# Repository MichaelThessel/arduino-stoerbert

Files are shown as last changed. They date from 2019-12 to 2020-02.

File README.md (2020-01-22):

# Intro

This repository contains the files required to build an easy to use MP3 player for small children.
This project is heavily inspired by [Hoerbert](https://en.hoerbert.com).

PCB CAD
Inside
Inside

Main components required to build:

* Arduino Uno
* Adafruit Music Maker shield
* Speaker
* Button PCB (see below)
* Volume Pot
* On/Off switch
* Battery holders
* Hookup wire

# Button PCB schematics

I created a custom PCB for the input buttons. The schematics for that are in the
cad directory in KiCad format. The Arduino UNO does not have enough GPIO pins
for the Music Maker shield, the volume pot, and 12 buttons. To reduce the amount
of GPIO pins required for the buttons I used 2 shift registers. That reduces the
amount of required pins for the buttons to 3.

I used the following components:

* [2x CD4021BC shift registers](http://www.redrok.com/CMOS_CD4021BC_8-StageStaticShiftRegister_Fairchild.pdf)
* [OmronB3F Buttons](https://www.amazon.ca/gp/product/B07CW1XJTS)
* as well as some 0805 1k resistors

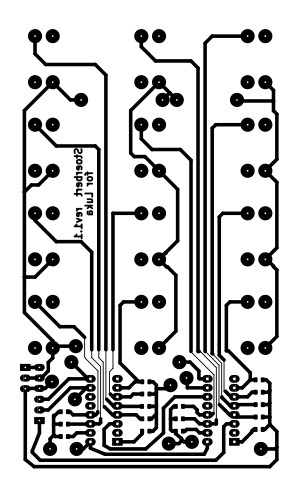
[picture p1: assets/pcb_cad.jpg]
PCB CAD

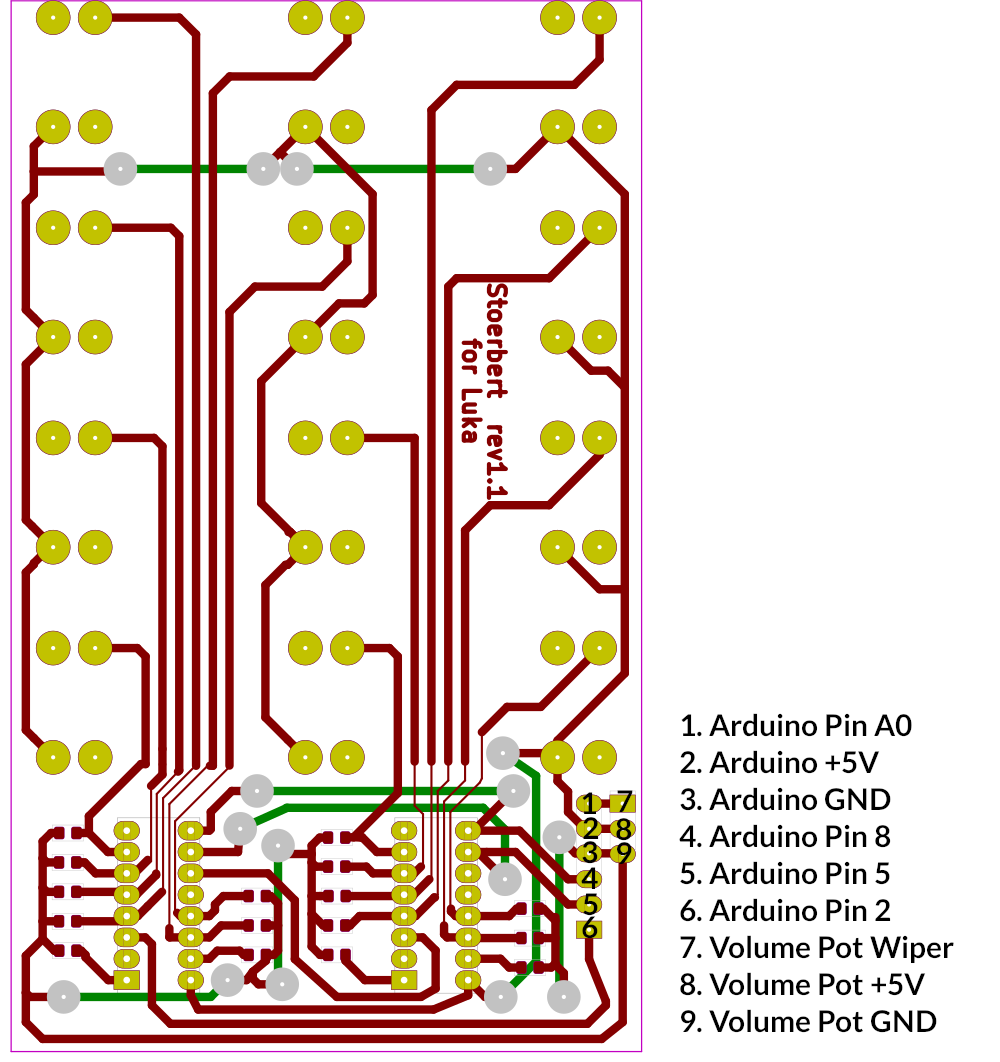
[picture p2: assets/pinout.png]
PCB Pinout

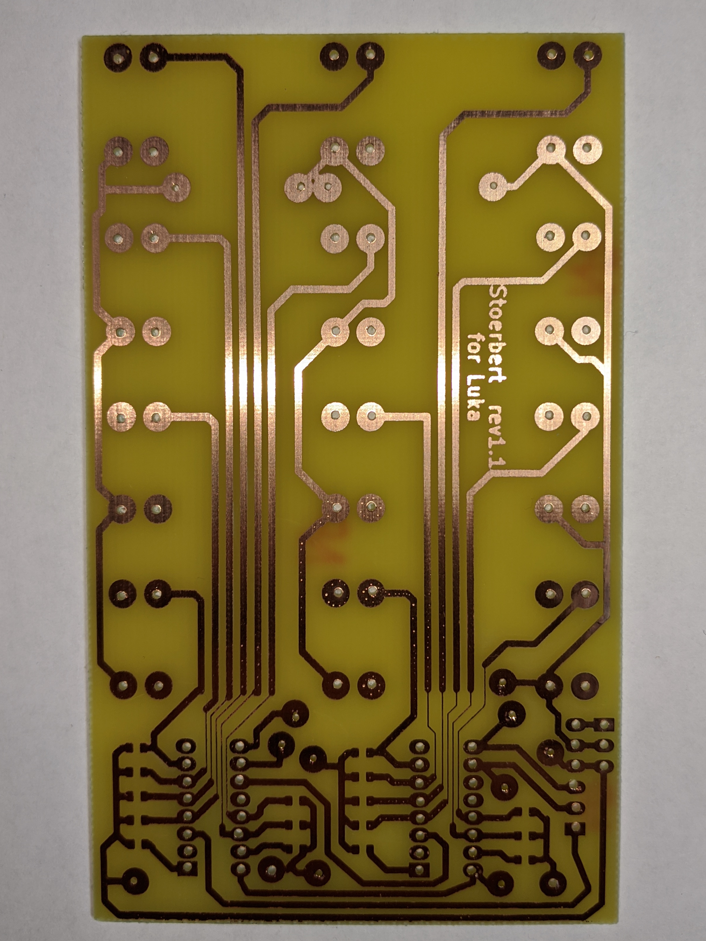
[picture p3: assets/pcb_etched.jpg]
PCB etched

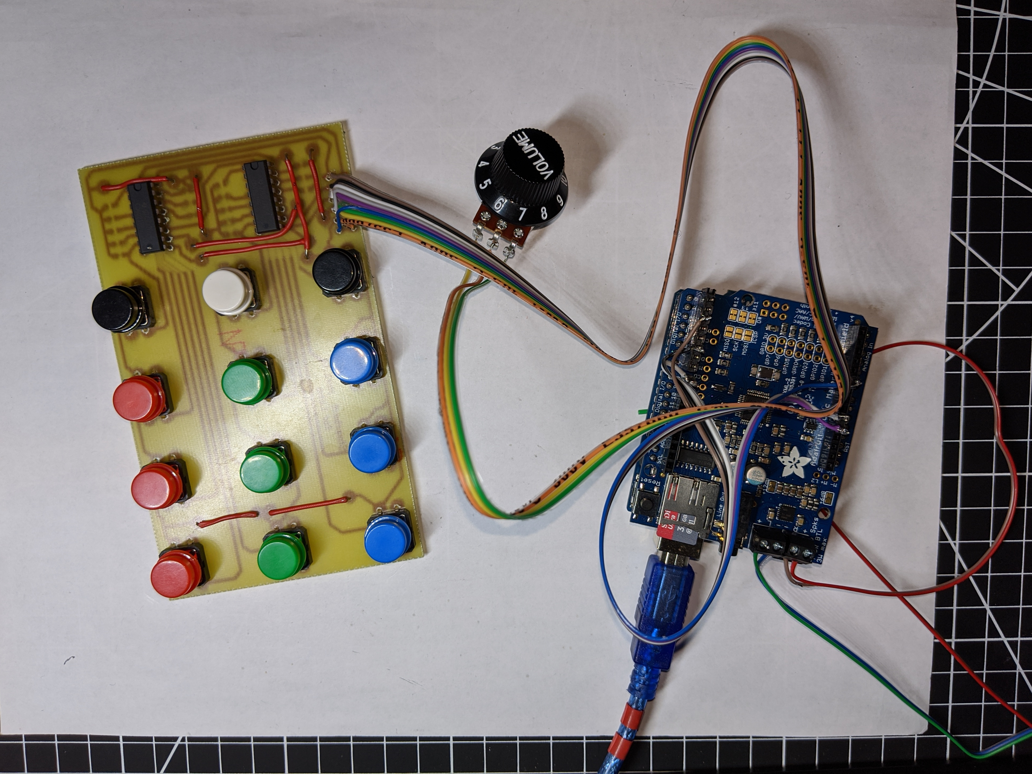
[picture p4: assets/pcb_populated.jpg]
PCB populated


If you want to etch the PCB yourself you can print this PDF on a transparency.
Make sure to use US letter sized transparencies if you use the PDF below.
Alternatively you can just create a new PDF from the KiCad layout.

[PCB transparency](/assets/pcb_cad.pdf)

I followed this [PCB etching process](https://www.youtube.com/watch?v=tWnfnt2rNO0)

# Button layout

## Regular mode

    [album 1]   [album 2]       [album 3]
    [album 4]   [album 5]       [album 6]
    [album 7]   [album 8]       [album 9]
    [prev]      [play_pause]    [next]

## God mode

    [1]         [2]             [3]
    [4]         [5]             [6]
    [7]         [8]             [9]
    [0]         [play_pause]    [next]

# God mode

The player supports 2 different modes. Regular mode and god mode.
In regular mode one album is assigned to each button. This is the default mode
and what the device is mainly intended for.
To add more functionality, god mode has been added. This mode allows to add an
alternative set of albums which makes it a handy MP3 player for parents as well.
In that mode instead of directly playing an album for each button press, the
buttons act as numerical input buttons. 2 buttons have to be pressed to select
an album. I.e. 4 - 2 to select album 42. Up to 99 albums are supported in
god mode.

To enter god mode the god mode sequence has to be pressed. The god mode sequence
is: prev - play_pause - play_ pause - next (regular mode keyboard layout). The
same sequence can be used to switch back to regular mode. When the sequence has
been entered correctly a short beep will sound.

# SD card

## Structure

The SD card needs to be formated with FAT32.

The root folder structure needs to be:

k01 ... k09 for the regular albums and

g01 ... g99 for the god mode albums

The files in each folder need to be named:

01.mp3 ... 99.mp3

i.e.

    /k06/01.mp3
    /k06/02.mp3
    /k06/03.mp3
    /k06/04.mp3
    /k06/05.mp3
    /k06/06.mp3

## Convert files to supported file format

    a=`find ./ -type f -name "*.mp3" | awk '{print "mv", "\""$0"\"", substr($0, 3, 2)".mp3;"}'`; eval $a

This only works if the files are named with the first 2 digits indicating their
track name already. I.e. `01-meshuggah-bleed.mp3`. A great alternative for batch
renaming the files is [Mp3Tag](https://www.mp3tag.de/en).

# Auto resume

The player will automatically resume the last played track after power off (if
powered off before an album finished playing).

# Power saving

To remind the user to turn of the device once the album has finished playing the
player will sound a short beep every 5 minutes once the last album has played.

# Mono mode

To keep the player compact and reduce power consumption this has been designed
to work with a single speaker. The Music Maker shield is configured to work in
mono mode. You can connect your speaker to either of the 2 speaker ports. In
case you want to build a stereo version you can simply remove these lines from
player.cpp

    // Enable mono mode
    vs1053.sciWrite(VS1053_REG_WRAMADDR, 0x1e09);
    vs1053.sciWrite(VS1053_REG_WRAM, 0x0001);

# Case build

I added an album of the full build on [Imgur](https://imgur.com/gallery/S2kZkn8)

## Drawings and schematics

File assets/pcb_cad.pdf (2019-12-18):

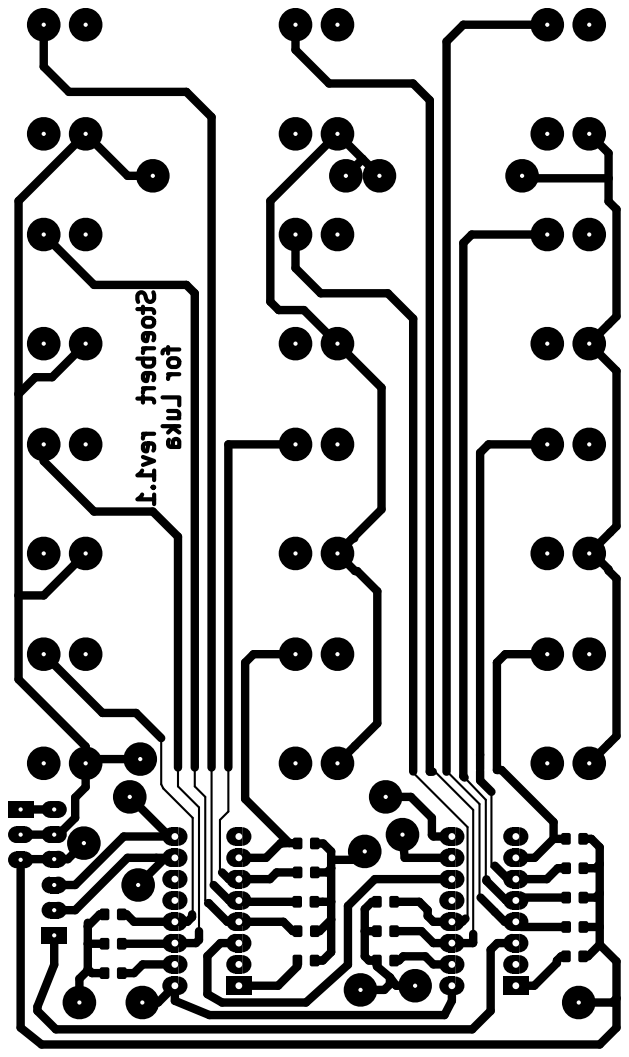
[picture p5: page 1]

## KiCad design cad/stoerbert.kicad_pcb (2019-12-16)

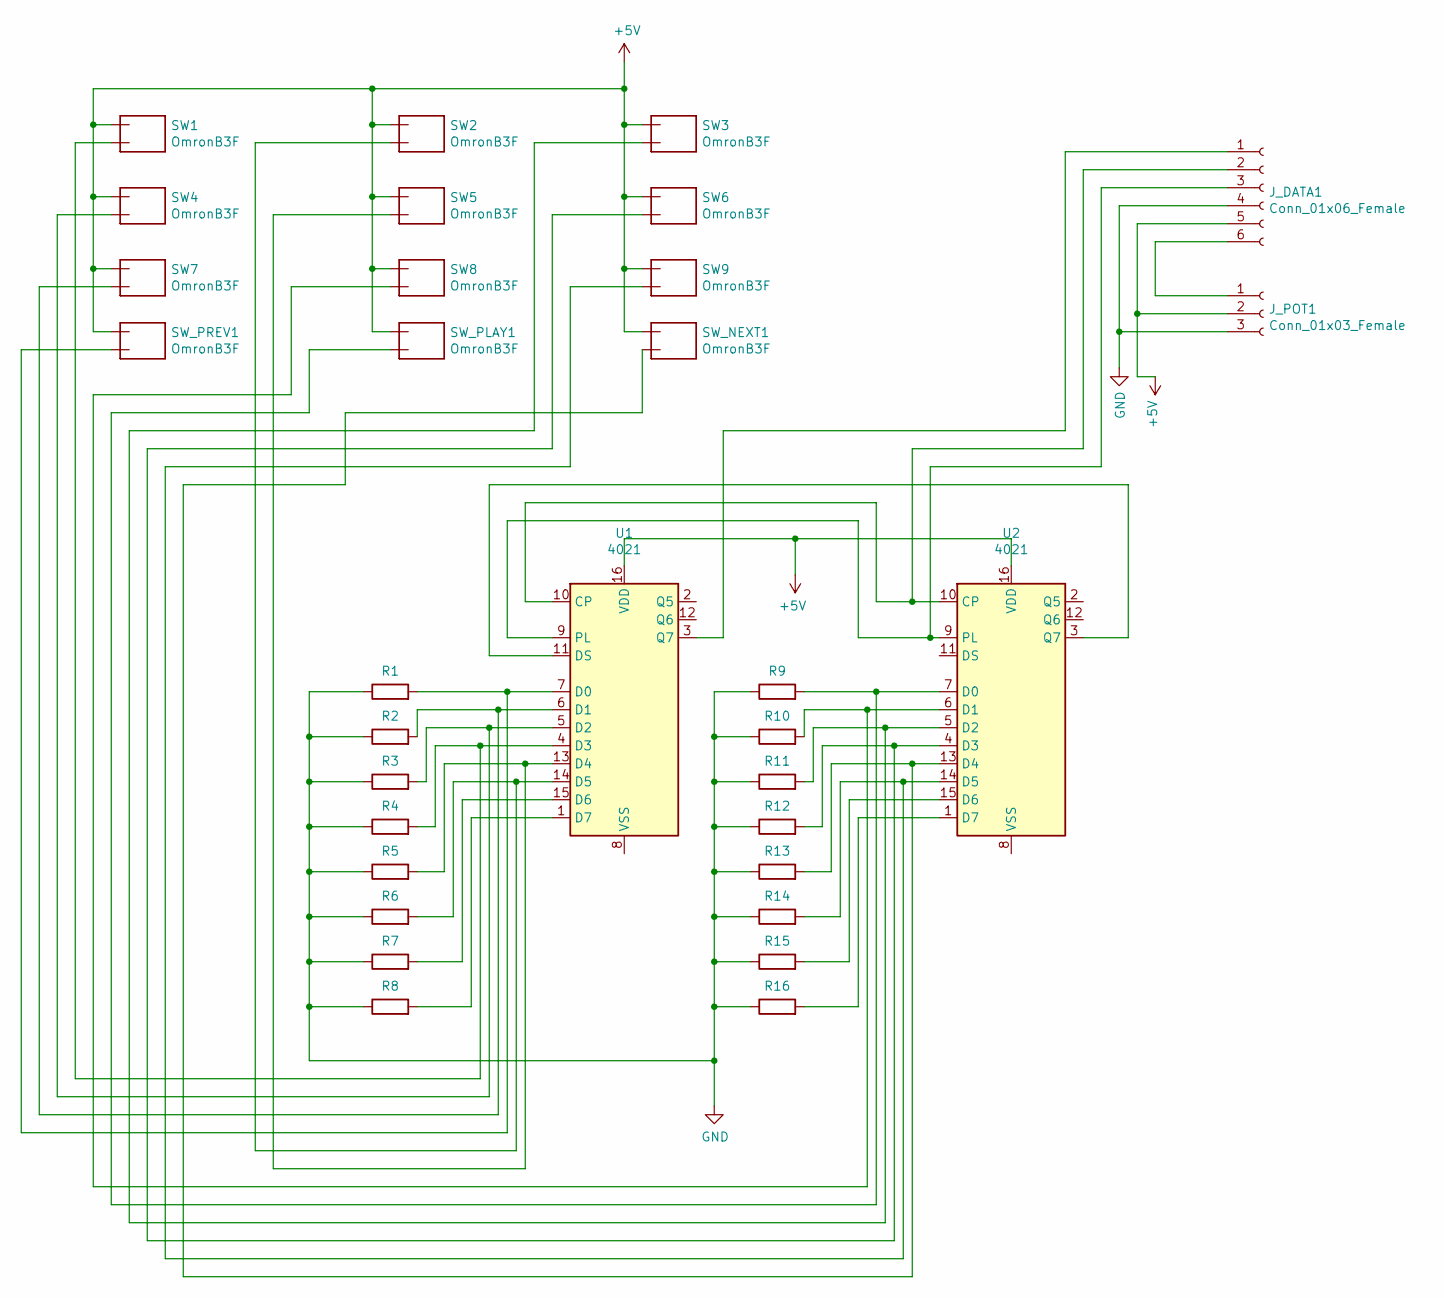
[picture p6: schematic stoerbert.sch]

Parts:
J_DATA1: Conn_01x06_Female; PinHeader_1x06_P2.00mm_Vertical
J_POT1: Conn_01x03_Female; PinHeader_1x03_P2.00mm_Vertical
R1: 1K; R_0805_2012Metric_Pad1.15x1.40mm_HandSolder
R2, R3: 1k; R_0805_2012Metric_Pad1.15x1.40mm_HandSolder
R4, R5, R6, R7, R8, R9, R10, R11, R12, R13, R14, R15, R16: R; R_0805_2012Metric_Pad1.15x1.40mm_HandSolder
SW1, SW2, SW3, SW4, SW5, SW6, SW7, SW8, SW9: OmronB3F; ToggleSwitch
SW_NEXT1: OmronB3F; ToggleSwitch
SW_PLAY1: OmronB3F; ToggleSwitch
SW_PREV1: OmronB3F; ToggleSwitch
U1, U2: 4021; DIP-16_W7.62mm_large

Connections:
+5V: J_DATA1.5, J_POT1.2, SW1.1, SW2.1, SW3.1, SW4.1, SW5.1, SW6.1, SW7.1, SW8.1, SW9.1, SW_NEXT1.1, SW_PLAY1.1, SW_PREV1.1, U1.16 (VDD), U2.16 (VDD)
GND: J_DATA1.4, J_POT1.3, R1.1, R2.1, R3.1, R4.1, R5.1, R6.1, R7.1, R8.1, R9.1, R10.1, R11.1, R12.1, R13.1, R14.1, R15.1, R16.1
unnamed: J_DATA1.1, U1.3 (Q7)
unnamed: J_DATA1.2, U1.10 (CP), U2.10 (CP)
unnamed: J_DATA1.3, U1.9 (PL), U2.9 (PL)
unnamed: J_DATA1.6, J_POT1.1
unnamed: R1.2, SW_PREV1.3, U1.7 (D0)
unnamed: R2.2, SW7.3, U1.6 (D1)
unnamed: R3.2, SW4.3, U1.5 (D2)
unnamed: R4.2, SW1.3, U1.4 (D3)
unnamed: R5.2, SW5.3, U1.13 (D4)
unnamed: R6.2, SW2.3, U1.14 (D5)
unnamed: R7.2, U1.15 (D6)
unnamed: R8.2, U1.1 (D7)
unnamed: R9.2, SW_PLAY1.3, U2.7 (D0)
unnamed: R10.2, SW8.3, U2.6 (D1)
unnamed: R11.2, SW3.3, U2.5 (D2)
unnamed: R12.2, SW6.3, U2.4 (D3)
unnamed: R13.2, SW_NEXT1.3, U2.13 (D4)
unnamed: R14.2, SW9.3, U2.14 (D5)
unnamed: R15.2, U2.15 (D6)
unnamed: R16.2, U2.1 (D7)
unnamed: U1.11 (DS), U2.3 (Q7)

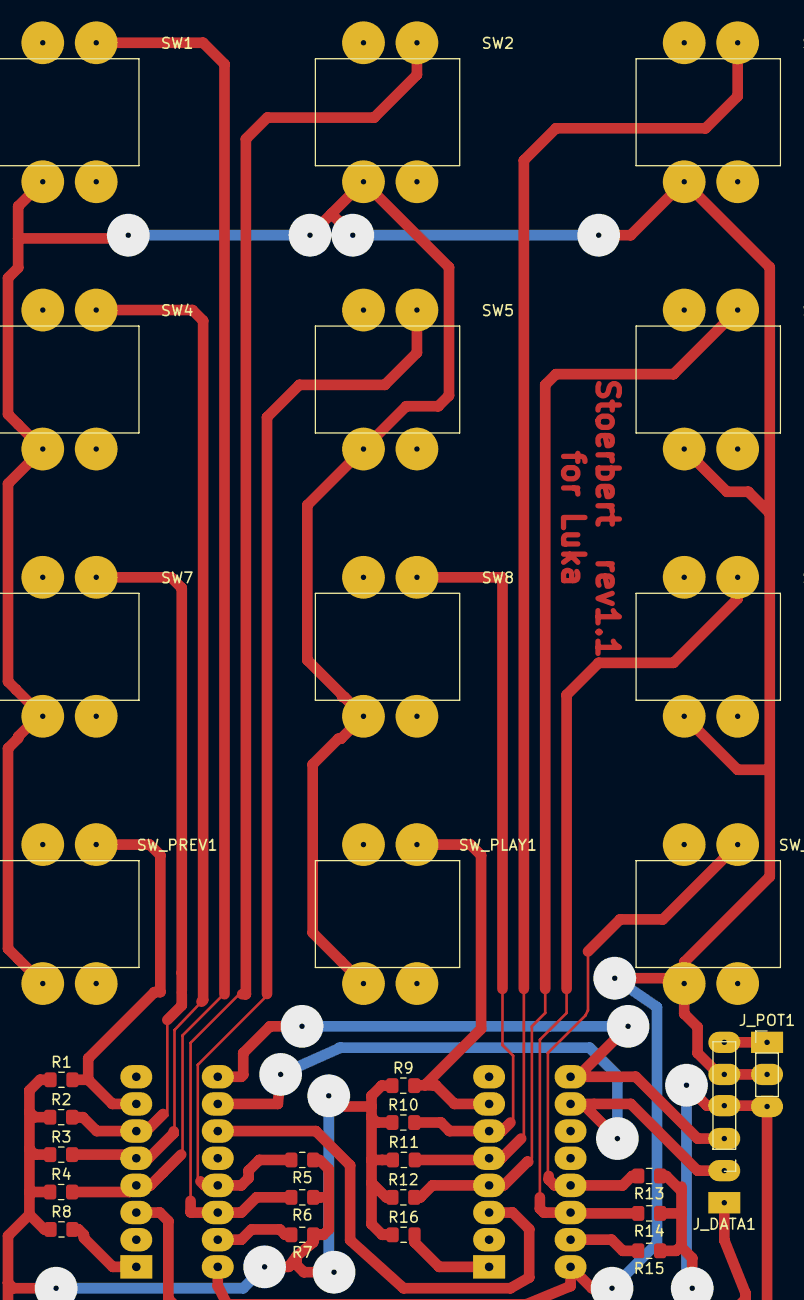
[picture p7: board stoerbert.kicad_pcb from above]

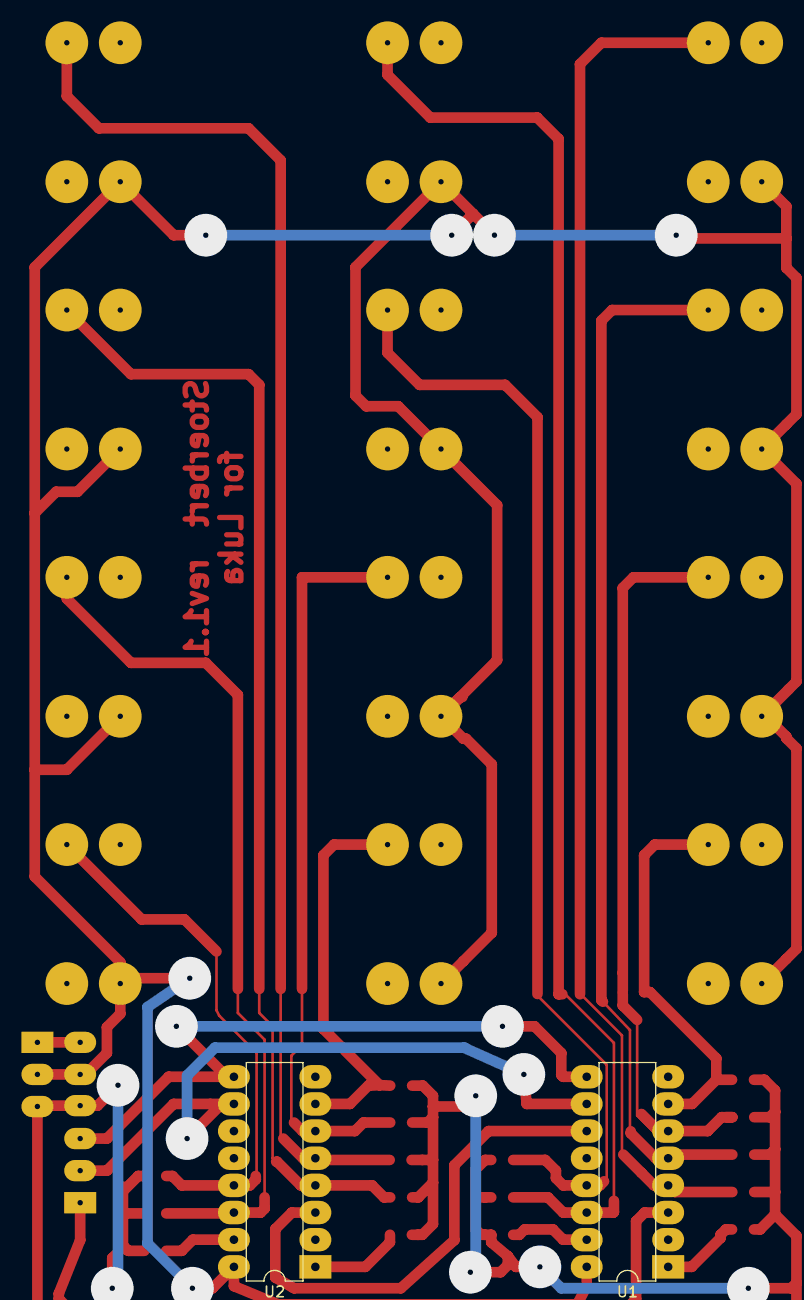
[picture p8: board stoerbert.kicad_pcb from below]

Board: 2 copper layers, 32 parts (2 on the bottom side), 23 nets.

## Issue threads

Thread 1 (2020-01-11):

Compile errors

GoremanX, 2020-01-11:
When trying to compile the sketch, the following warnings come up (full file path edited to protect privacy):

```sketch\player.cpp: In function 'void loadAlbum()':

sketch\player.cpp:89:35: warning: invalid conversion from 'void*' to 'char*' [-fpermissive]

         p.album[sequence] = malloc(strlen(entry.name()) + 1);

                             ~~~~~~^~~~~~~~~~~~~~~~~~~~~~~~~~

sketch\player.cpp: In function 'void powerReminder()':

sketch\player.cpp:235:39: warning: large integer implicitly truncated to unsigned type [-Woverflow]

         musicPlayer.sineTest(1000, 500);

                                       ^

sketch\player.cpp: In function 'void setupPlayer()':

sketch\player.cpp:410:63: warning: invalid conversion from 'const short unsigned int*' to 'const uint16_t* {aka const unsigned int*}' [-fpermissive]

     vs1053.applyPatch(plugin, sizeof(plugin)/sizeof(plugin[0]));

                                                               ^

In file included from sketch\player.cpp:4:0:

x:\path\to\Adafruit_VS1053_Library/Adafruit_VS1053.h:132:8: note:   initializing argument 1 of 'void Adafruit_VS1053::applyPatch(const uint16_t*, uint16_t)'

   void applyPatch(const uint16_t *patch, uint16_t patchsize);

        ^~~~~~~~~~
```

Compilation appears to complete despite these warnings, and upload to Arduino Uno proceeds as expected.

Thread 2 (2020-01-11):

Bootloop trying to run compiled sketch

GoremanX, 2020-01-11:
When the sketch is compiled and uploaded, this is the output from the Serial Monitor:

```VS1053 found
Loaded album from EEPROM: ⸮⸮⸮
Loaded track from EEPROM: 255
Resuming playback
Loading files from directory: /⸮⸮⸮/
File ⸮VS1053 found
Loaded album from EEPROM: ⸮⸮⸮
Loaded track from EEPROM: 255
Resuming playback
Loading files from directory: /⸮⸮⸮/
File ⸮VS1053 found
Loaded album from EEPROM: ⸮⸮⸮
Loaded track from EEPROM: 255
Resuming playback
```
Music never starts playing. It appears to just reboot forever. The 2GB micro SD card is formatted FAT32 and has directories 1 through 9, each one containing files 01.mp3 through 05.mp3. I also tried naming the directories k01 through k09 as specified in readme.MD without success, though the code in player.cpp seems to imply that the directory  naming should actually be 1 through 9 (without k0 in front). The Music Maker shield functions fine and plays music from the same SD card when using the player_simple and player_interrupts example sketches.

MichaelThessel, 2020-03-09:
Fixed in this commit: 8887e05db1dfca9f5cc15f7338e26f2eef499aae

Closed 2020-03-09.

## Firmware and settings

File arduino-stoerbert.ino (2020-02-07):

#include <Adafruit_VS1053.h>

#include "pins.h"
#include "debug.h"
#include "commands.h"
#include "sr.h"
#include "player.h"
#include "power.h"

extern sr sr1;
extern sr sr2;
extern srAssignments sra;

// ##################################
// Setup
// ##################################
void setup() {
    #ifdef DEBUG
    Serial.begin(9600);
    #endif

    setupPower();
    setupPlayer();
    setupSr();
}

// ##################################
// Main loop
// ##################################

void loop() {
    watchdogReset();

    #ifdef DEBUG
    if (Serial.available()) {
        char c = Serial.read();
        handleCommand(c);
    }
    #endif

    handlePlayer();
    handleButtons();
}

// ##################################
// Button handling
// ##################################
void handleButtons() {
    // Handle button shift registers
    sr1.state = srShiftIn(true);
    sr2.state = srShiftIn(false);

    if (debounce(&sr1)) {
        if (sr1.state & sra.button2) { handleCommand(COMMAND2); }
        if (sr1.state & sra.button3) { handleCommand(COMMAND3); }
        if (sr1.state & sra.button5) { handleCommand(COMMAND5); }
        if (sr1.state & sra.button6) { handleCommand(COMMAND6); }
        if (sr1.state & sra.button9) { handleCommand(COMMAND9); }
        if (sr1.state & sra.buttonNext) { handleCommand(COMMAND_NEXT); }
    }

    if (debounce(&sr2)) {
        if (sr2.state & sra.button1) { handleCommand(COMMAND1); }
        if (sr2.state & sra.button4) { handleCommand(COMMAND4); }
        if (sr2.state & sra.button7) { handleCommand(COMMAND7); }
        if (sr2.state & sra.button8) { handleCommand(COMMAND8); }
        if (sr2.state & sra.buttonPlayPause) { handleCommand(COMMAND_PLAY_PAUSE); }
        if (sr2.state & sra.buttonPrevious) { handleCommand(COMMAND_PREVIOUS); }
    }
}

// ##################################
// Commands
// ##################################
void handleCommand(char c) {
    switch (c) {
        // Start playing
        case COMMAND1:
        case COMMAND2:
        case COMMAND3:
        case COMMAND4:
        case COMMAND5:
        case COMMAND6:
        case COMMAND7:
        case COMMAND8:
        case COMMAND9:
            DPRINTF("Received Command: PLAY ");
            DPRINTLN(c);
            if (setAlbum(c)) {
                playAlbum();
            }
            break;

        // GOD mode !!!
        case COMMAND_GOD_MODE:
            DPRINTLNF("Received Command: God Mode");
            toggleGodMode();
            break;

        // Toggle play/pause
        case COMMAND_PLAY_PAUSE:
            detectGodMode(c);

            DPRINTLNF("Received Command: TOGGLE PLAY/PAUSE");
            togglePlayPause();
            break;

        // Next track
        case COMMAND_NEXT:
            if (detectGodMode(c)) {
                break;
            }

            DPRINTLNF("Received Command: NEXT TRACK");
            playNextTrack();
            break;

        // Previous track / COMMAND0 in god mode
        case COMMAND_PREVIOUS:
            detectGodMode(c);

            if (isGodMode()) {
                setAlbum(COMMAND0);
                break;
            }

            DPRINTLNF("Received Command: PREVIOUS TRACK");
            playPreviousTrack();
            break;

        // Increase volume
        case COMMAND_INCREASE_VOLUME:
            DPRINTLNF("Received Command: VOLUME +");
            increaseVolume();
            break;

        // Decrease volume
        case COMMAND_DECREASE_VOLUME:
            DPRINTLNF("Received Command: VOLUME -");
            decreaseVolume();
            break;

        // Ignore newlines
        case '\n':
            break;

        // Log invalid commands
        default:
            DPRINTF("Invalid command: ");
            DPRINTLN(c);
            break;
    }
}

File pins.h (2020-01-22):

#ifndef PINS_H
#define PINS_H

#define PIN_VS1053_SHIELD_RESET -1 // VS1053 reset pin (unused!)
#define PIN_VS1053_SHIELD_CS 7 // VS1053 chip select pin (output)
#define PIN_VS1053_SHIELD_DCS 6 // VS1053 Data/command select pin (output)
#define PIN_VS1053_CARDCS 4 // Card chip select pin
#define PIN_VS1053_DREQ 3 // VS1053 Data request, ideally an Interrupt pin
#define PIN_VOLUME A0 // Volume knob pin
#define PIN_SR_DATA 2 // Shift register data pin
#define PIN_SR_CLOCK 5 // Shift register clock pin
#define PIN_SR_LATCH 8 // Shift register latch pin

#endif

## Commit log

2019-11-24 Corrected album track counting
    [stoerbert.ino]
2019-11-26 Added support for button shift registers
2019-11-27 Added button debouncing
2019-11-27 Added PCB project files
    [stoerbert.kicad_pcb, stoerbert.sch]
2019-11-29 Fixed debounce delay overflow
    [stoerbert.ino]
2019-11-29 Finalized button handling
2019-11-30 Moved pin and debug definitions to header files
2019-12-02 Added power saving settings
2019-12-03 Fixed button mapping
2019-12-04 Fixed access to uninitialized musicPlayer
    [player.cpp]
2019-12-08 Added PCB design files
2019-12-11 Added power reminder
2019-12-16 Updated PCB
    [stoerbert.kicad_pcb, stoerbert.sch]
2019-12-17 Changed button assignments
2019-12-17 Reset playback before loading album
    [player.cpp]
2019-12-18 Added power saving section
2019-12-19 Disable VS1053 ADC
2020-01-22 Fixed error in comment
    [pins.h]
2020-02-07 Fixed reset lopp when EEPROM has no valid state
    [arduino-stoerbert.ino, player.cpp]
